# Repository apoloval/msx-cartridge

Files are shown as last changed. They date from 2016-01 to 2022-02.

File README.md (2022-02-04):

# MSX Cartridge

Some hardware specs (schematics + PCB designs) to build cartridges for MSX system.

This PCB can be used to mimic old cartridges for the MSX system. 
It will fit any ROM dump <64kb. Dumps larger than 64kb need a mapper, not implemented in this version.

EPROM supported is the SST39 family that can be bought for around 1.5€. This EPROM can be programmed with a standard TL866 programmer.







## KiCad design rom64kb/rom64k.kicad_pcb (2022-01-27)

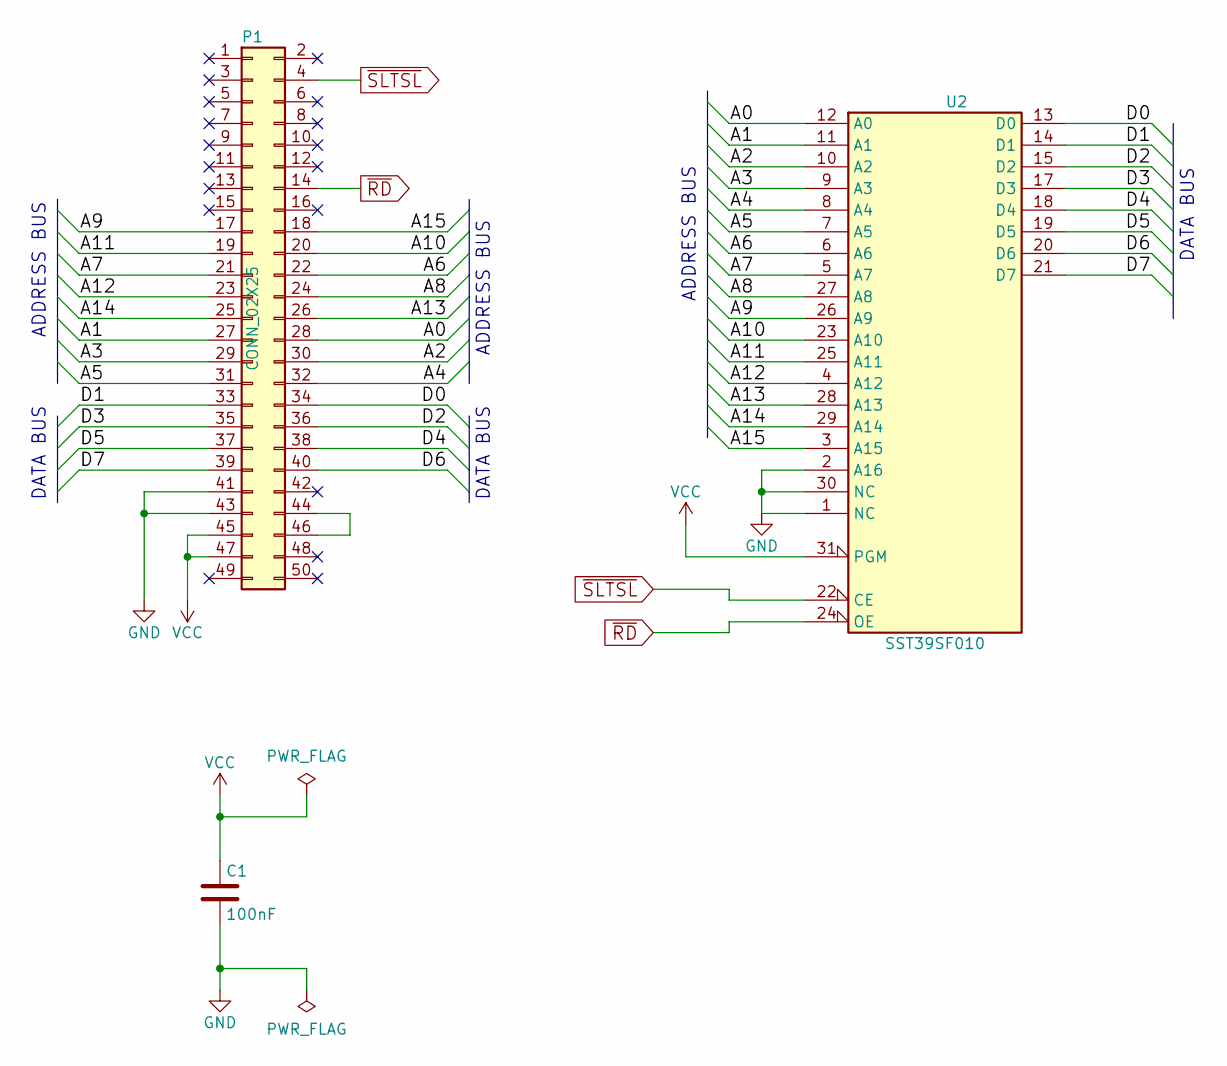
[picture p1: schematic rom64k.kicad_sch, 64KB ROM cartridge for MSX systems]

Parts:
C1: 100nF; C_Disc_D6_P5
P1: CONN_02X25; msx_cartridge
U2: SST39SF010; DIP-32_W15.24mm

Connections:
/A0: P1.28, U2.12 (A0)
/A1: P1.27, U2.11 (A1)
/A2: P1.30, U2.10 (A2)
/A3: P1.29, U2.9 (A3)
/A4: P1.32, U2.8 (A4)
/A5: P1.31, U2.7 (A5)
/A6: P1.22, U2.6 (A6)
/A7: P1.21, U2.5 (A7)
/A8: P1.24, U2.27 (A8)
/A9: P1.17, U2.26 (A9)
/A10: P1.20, U2.23 (A10)
/A11: P1.19, U2.25 (A11)
/A12: P1.23, U2.4 (A12)
/A13: P1.26, U2.28 (A13)
/A14: P1.25, U2.29 (A14)
/A15: P1.18, U2.3 (A15)
/D0: P1.34, U2.13 (D0)
/D1: P1.33, U2.14 (D1)
/D2: P1.36, U2.15 (D2)
/D3: P1.35, U2.17 (D3)
/D4: P1.38, U2.18 (D4)
/D5: P1.37, U2.19 (D5)
/D6: P1.40, U2.20 (D6)
/D7: P1.39, U2.21 (D7)
GND: C1.2, P1.41, P1.43, U2.1 (NC), U2.2 (A16), U2.16 (GND), U2.30 (NC)
unnamed: P1.44, P1.46
VCC: C1.1, P1.45, P1.47, U2.31 (PGM), U2.32 (VCC)
~RD: P1.14, U2.24 (OE)
~SLTSL: P1.4, U2.22 (CE)

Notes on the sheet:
DATA BUS
ADDRESS BUS

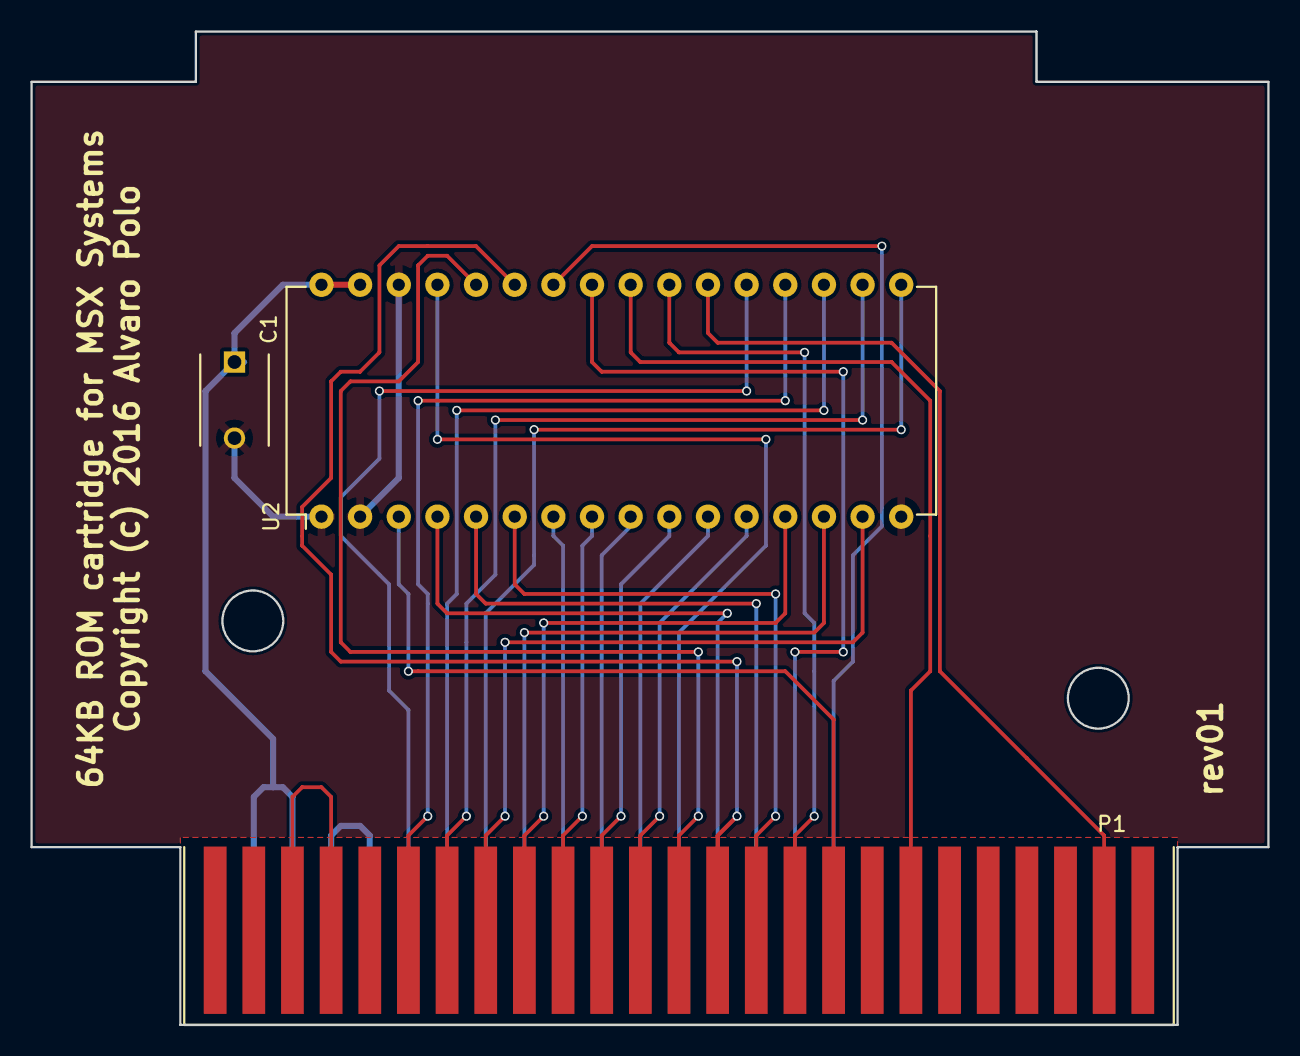
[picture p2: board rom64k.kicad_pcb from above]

Board: 2 copper layers, 81.3 x 65.3 mm, 3 parts (0 on the bottom side), 29 nets.

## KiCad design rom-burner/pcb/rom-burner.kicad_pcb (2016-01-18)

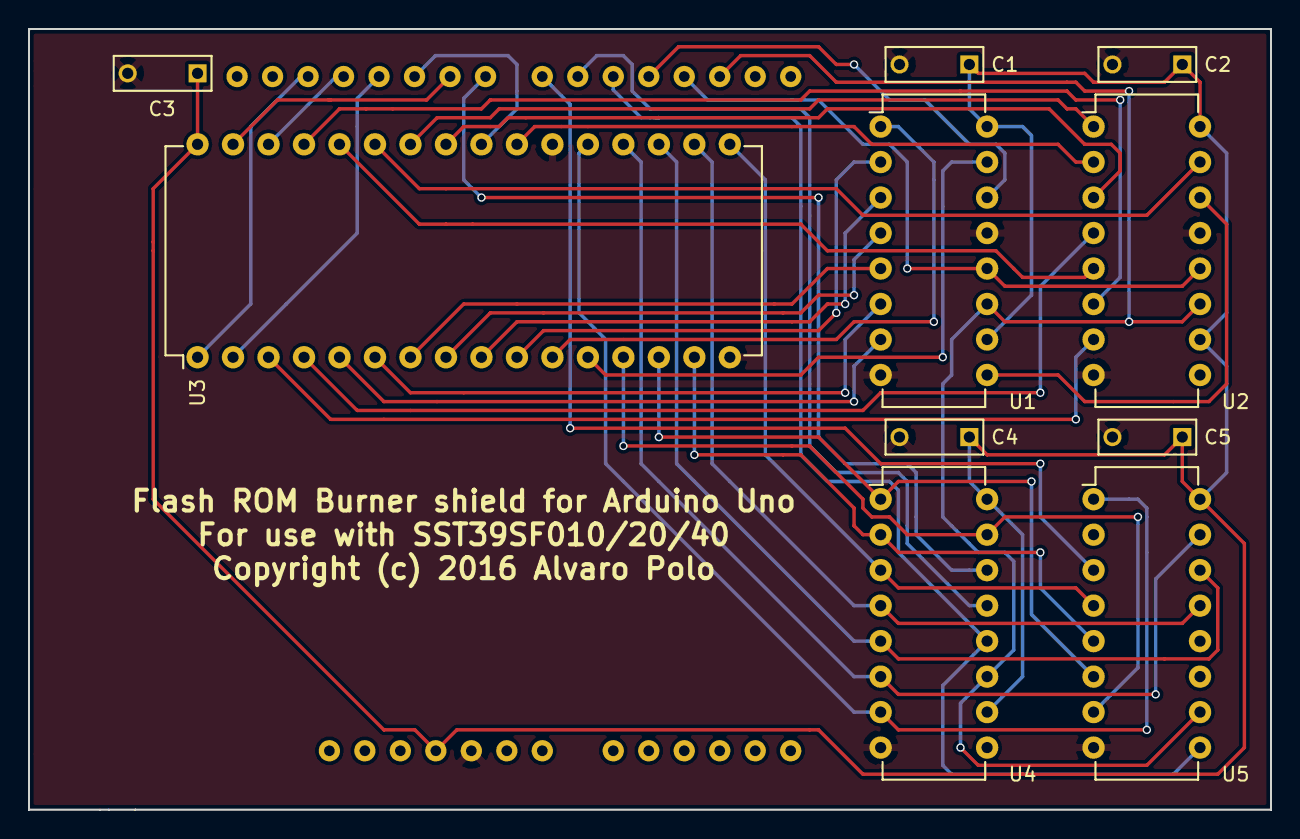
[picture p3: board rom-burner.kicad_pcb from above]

Board: 2 copper layers, 88.9 x 55.9 mm, 11 parts (0 on the bottom side), 39 nets.

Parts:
C1, C2, C3, C4, C5: 100nF; C_Rect_L7_W2.5_P5
U1, U2, U4: 74HC595; DIP-16_W7.62mm
U3: SST39SF010/20/40; DIP-32_W15.24mm
U5: 4021; DIP-16_W7.62mm
U6: Arduino_Uno_shield; arduino_uno_shield

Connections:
/A0: U1.15, U3.12
/A1: U1.1, U3.11
/A2: U1.2, U3.10
/A3: U1.3, U3.9
/A4: U1.4, U3.8
/A5: U1.5, U3.7
/A6: U1.6, U3.6
/A7: U1.7, U3.5
/A8: U2.15, U3.27
/A9: U2.1, U3.26
/A10: U2.2, U3.23
/A11: U2.3, U3.25
/A12: U2.4, U3.4
/A13: U2.5, U3.28
/A14: U2.6, U3.29
/A15: U2.7, U3.3
/DQ0: U3.13, U4.15, U5.7
/DQ1: U3.14, U4.1, U5.6
/DQ2: U3.15, U4.2, U5.5
/DQ3: U3.17, U4.3, U5.4
/DQ4: U3.18, U4.4, U5.13
/DQ5: U3.19, U4.5, U5.14
/DQ6: U3.20, U4.6, U5.15
/DQ7: U3.21, U4.7, U5.1
ADDR16: U3.2, U6.12
ADDR17: U3.30, U6.13
ADDR18: U3.1, U6.14
ADDR_DAT: U1.14, U6.5
ADDR_LATCH: U1.12, U2.12, U6.4
CLOCK: U1.11, U2.11, U4.11, U5.10, U6.3
DATA_DIR: U4.13, U6.7
DATA_IN: U5.3, U6.8
DATA_LATCH: U4.12, U5.9, U6.6
DATA_OUT: U4.14, U6.9
GND: C1.2, C2.2, C3.2, C4.2, C5.2, U1.8, U1.13, U2.8, U2.13, U3.16, U3.22, U4.8, U5.8, U6.21
unnamed: U1.9, U2.14
OE: U3.24, U6.11
VCC: C1.1, C2.1, C3.1, C4.1, C5.1, U1.10, U1.16, U2.10, U2.16, U3.32, U4.10, U4.16, U5.16, U6.20
WE: U3.31, U6.10

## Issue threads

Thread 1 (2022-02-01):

How to map ROM files to the 128 K flash

alex3331, 2022-02-01:
Hi, How many ROM images can I put on 128 k flash?
Can I put, say four of 32 k ROMS?

apoloval, 2022-02-03:
The 128KB cartridge is just a proof of concept. It was never tested. So first of all: USE IT AT YOUR OWN RISK!

Answering the question. The 3 jumpers are used to define the base address of the ROM that will be mapped by the cartridge, shifted 14 bits to the left. The goal of this is to write several games in the same cartridge, and control which one to use with the jumpers.

The following table summarizes the ROM offset mapped for each jumper value:

| Jumper value | ROM offset |
|--------------|------------|
| 0b000 | 0x00000 |
| 0b001 | 0x04000 |
| 0b010 | 0x08000 |
| 0b011 | 0x0C000 |
| 0b100 | 0x10000 |
| 0b101 | 0x14000 |
| 0b110 | 0x18000 |
| 0b111 | 0x1C000 |

How can you take advantage of this? Well, typically cartridges without mappers have a 16KB or 32KB ROM that respond to memory access at 0x4000 or 0x8000. So you could arrange your ROM data as follows:

| 16KB segment of ROM | Content |
| ---- |--- |
| 0 | Nothing, likely never used. |
| 1 | Game A page 1 (0x4000) |
| 2 | Game A page 2 (0x8000) |
| 3 | Game B page 1 (0x4000) |
| 4 | Game B page 2 (0x8000) |
| 5 | Game C page 2 (0x8000) |
| 6 | Game D page 1 (0x4000) |
| 7 | Game D page 2 (0x8000) |

In this example, games A, B and D are 32KB ROMS, while game C is just 16KB. You could play each one using the following jumper config

| Game | Jumper config |
| --- | --- |
| A | 0b000 |
| B | 0b010 |
| C | 0b011 |
| D | 0b100 |

The point is that if you want some page to be mapped at 0x4000, you have to calculate `ROM segment - 1` as jumper config. And if you want to map it at 0x8000, it is `ROM segment - 2`.

That's how you use that 128KB cartridge.

However, it is very likely this is not what you are looking for. But a kind of MegaROM with certain kind of mapper. If that's the case, you are lucky! I've been recently working on a solution to have a Konami-compatible (and also ASCII-compatible) cartridge of 128KB, and maybe more. You may find it in the `konami` Git branch. But it is still WIP. Watch this repo to receive news about its progress.

Everything clear now?

alex3331, 2022-02-03:
Yes, thank you for the clarification

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
--
Alex Shakhnovich

apoloval, 2022-02-04:
Alright! Please note the current method of mapping sections of the ROM might be not the best. And it could change in the future.

Closing this. If you have more questions, feel free to reopen.

Closed 2022-02-04.

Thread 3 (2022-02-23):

Mapping of Memory

alex3331, 2022-02-23:
After considering  at how 74LS283 works, I do  see that  SW3 with 128 K EEPROM is not effectively used.  Right now there are two 64 kB banks, each of them can be addressed at 0000, 4000, 8000  or C000. This is only 8 combinations of  A14, A15  and MA14, MA15, MA16  switches out of available 16.
It is possible to use 256 k or 512 k EEPROM. By the way - it is a lot easier and cheaper to buy SST 39SF040 (512 k) - other IC's (010 and 020) are backordered indefinitely. Let me know what you think.  8 and 32K games work fine, I am experimenting with larger games.
Let me know if I am wrong. Thanks

apoloval, 2022-04-21:
Yes, totally right. We are using only 3-bits to indicate the 16KB offset in the ROM. That only covers a ROM address space of 128KB. By adding another bit we could handle 256KBs.

However, let me insist that the 128KB design is incomplete. It was never tested in production. And not intended for use.

alex3331, 2022-04-21:
Hello,
I finally made this design work. I can put four programs up to 32 k each into a 128 k ROM. All I had to do is to change polarity around DIP switches. Everything works fine. I added 2 more DIP switches and now can use 512 k ROM to store and run 16 games. I need to update PCB but I do not have all of your libraries. I can share an updated schematics if you are interested.

Sent from my iPad

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

alex3331, 2022-04-21:
If you are interested - this works.

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

--
Alex Shakhnovich

apoloval, 2022-04-25:
What do you mean by _change polarity around DIP switches_?

retrolab-ad, 2022-10-14:
Hello.
Is there any 128k schematic working to share?
Thanks

apoloval, 2022-10-15:
> Is there any 128k schematic working to share?

Sorry, not yet.

retrolab-ad, 2022-10-15:
Gracias

El ds., 15 d’oct. 2022, 12:27, Alvaro Polo ***@***.***> va
escriure:

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

elosha, 2023-02-03:
@alex3331
> All I had to do is to change polarity around DIP switches.

Could you please elaborate on that what exactly you mean? Thanks 😃

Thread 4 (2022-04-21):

Is there a way to load the breakout project in Kicad?

alex3331, 2022-04-21:
Unable to load. because .sch file is shown as not valid.

apoloval, 2022-04-25:
What version of KiCAD are you using? This project was generated with KiCAD 6.

I am progressively migrating the rest of projects to that version. My recommendation is to update if you didn't yet.

apoloval, 2023-02-03:
I hope my last comment answered your question. Please feel free to reopen the issue otherwise.

Closed 2023-02-03.

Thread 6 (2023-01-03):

Less than 64KB on 64KB cartridge PCB

elosha, 2023-01-03:
_Edit: Nevermind, it seems I've ordered an old revision with 27C512 back then … but still interested to learn ;)_

I've already ordered your 64KB cartridge PCBs, but seeing other cartridge PCBs made me suspicious.

1. They require setting jumpers in order to use a 512Kbit ROM because of memory mapping, and other jumpers to use smaller ROMs because of different pinouts. Your layout even suggests a SST39SF010 and stays completely jumperless. How does memory mapping work?

Additionally, I've still got smaller EPROMs available. You wrote that ROMs with less than 64K are ok. Questions regarding replacing the SST39SF010, since pinouts are incompatible:

2. Is it correct that disconnecting pin `#30 NC` (≙ `#28 Vcc` on a DIP28 footprint) from the circuit and connecting it to _Vcc_ instead (making it a supply pin) simply allows using a 27C512, if aligned to the right?
3. Going further, connecting `#3 A15` (≙ `#1 Vpp` on DIP28) to _GND_ and `#29 A14` (≙ `#27 /PGM` on DIP28) to _Vcc_ instead would allow to fit a 27C256? But would it work in MSX memory mapping context?

apoloval, 2023-01-10:
There is no selectable memory mapping in this design. The first 64KBs of ROM memory are mapped to the 64KB memory space of the cartridge slot. The rest of ROM memory is not mapped. This is the simplest design ever possible for a ROM cartridge.

This was designed with the SST39SF0x0 chip in mind. For other ROM chips that use a different pinout, connections should be rewired accordingly, yes.

apoloval, 2023-02-03:
I hope my last comment answered your question. Please feel free to reopen the issue otherwise.

Closed 2023-02-03.

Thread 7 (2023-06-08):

Just a question..

atssada, 2023-06-08:
First of all, thank you so much sharing! really appreciated.

I ordered 64KB ROM PCB, and prepared SST 39SF010A (1MB Flash)..

And I programmed 32K rom by TL866  programmer (all default), and programming itself was successful..

But MSX can not run the 32K rom..

Any advice for me to investigate further?

Any MSX program to flash rom file?

Best,
Kim.

apoloval, 2023-06-08:
Perhaps you had written the ROM image to the wrong addresses.

The PCB is mapping the ROM memory in the 64KB address space of the cartridge slot as is. This means the address 0000h of the ROM chip corresponds to the address 0000h of the slot address.

The MSX, during BIOS boot, looks for a bootable program of slots only on memory pages 1 (at 4000h) and 2 (at 8000h). If you had written your program on address 0000h, it will never boot.

Try to manipulate your ROM image such that it is extended to 64KB, so it contains:
- 0000h to 3FFFh: fill with zeroes
- 4000h to 7FFFh: your program
- 8000h to FFFFh: fill with zeroes

For a program that expects to run on page 1. Or the following if it expects to run on page 2:
- 0000h to 7FFFh: fill with zeroes
- 8000h to BFFFh: your program
- C000h to FFFFh: fill with zeroes

Then write that ROM image to the 39SF and try again.

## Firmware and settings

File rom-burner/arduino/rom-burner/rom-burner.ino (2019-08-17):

#define PIN_CLOCK         2
#define PIN_ADDR_LATCH    3
#define PIN_ADDR_OUT      4
#define PIN_DATA_LATCH    5
#define PIN_DATA_READ     6
#define PIN_DATA_IN       7
#define PIN_DATA_OUT      8
#define PIN_WE            9
#define PIN_OE            10
#define PIN_ADDR16        11
#define PIN_ADDR17        12
#define PIN_ADDR18        13

#define SECTOR_SIZE       4096

#define COMMAND_READ      0
#define COMMAND_ERASE     1
#define COMMAND_WRITE     2
#define COMMAND_ERASEALL  3

#define SERIAL_BAUDRATE 921600

/** Put the given address in the bus through shift out registers. */
void put_addr(unsigned long addr) {
  digitalWrite(PIN_ADDR_LATCH, LOW);
  digitalWrite(PIN_CLOCK, LOW);
  shiftOut(PIN_ADDR_OUT, PIN_CLOCK, MSBFIRST, (byte) (addr >> 8));
  shiftOut(PIN_ADDR_OUT, PIN_CLOCK, MSBFIRST, (byte) addr);
  digitalWrite(PIN_ADDR16, bitRead(addr, 16));
  digitalWrite(PIN_ADDR17, bitRead(addr, 17));
  digitalWrite(PIN_ADDR18, bitRead(addr, 18));
  digitalWrite(PIN_ADDR_LATCH, HIGH);
}

/** Put the given data in the bus through shift out registers. */
void put_data(byte data) {
  digitalWrite(PIN_DATA_LATCH, LOW);
  digitalWrite(PIN_CLOCK, LOW);
  shiftOut(PIN_DATA_OUT, PIN_CLOCK, MSBFIRST, (byte) data);
  digitalWrite(PIN_DATA_LATCH, HIGH);
}

/** Get data from the data bus. */
byte get_data() {
  digitalWrite(PIN_OE, LOW);
  digitalWrite(PIN_CLOCK, HIGH);
  digitalWrite(PIN_DATA_LATCH, HIGH);
  digitalWrite(PIN_DATA_LATCH, LOW);
  digitalWrite(PIN_OE, HIGH);
  return shiftIn(PIN_DATA_IN, PIN_CLOCK, MSBFIRST);
}

/** Send a command to the ROM device. */
void send_cmd_seq(unsigned long* addr, byte* data, unsigned len) {
  digitalWrite(PIN_DATA_READ, LOW);
  digitalWrite(PIN_OE, HIGH);
  for (int i = 0; i < len; i++) {
    put_addr(addr[i]);
    digitalWrite(PIN_WE, LOW);
    put_data(data[i]);
    digitalWrite(PIN_WE, HIGH);
  }
  digitalWrite(PIN_DATA_READ, HIGH);
}

/** Read the content of given ROM device address. */
byte read_addr(unsigned long addr) {
  put_addr(addr);
  return get_data();
}

/** Wait for write/erase operation using data polling method. */
void wait_datapolling(byte data) {
  for (;;) {
    byte recv = get_data();
    if ((recv & 0x80) == (data & 0x80))
      return;
  }
}

/**
 * Write the content of the given ROM device address
 * with the given byte.
 */
void write_addr(unsigned long addr, byte data) {
  unsigned long addr_seq[] = { 0x5555, 0x2aaa, 0x5555, addr };
  byte data_seq[] = { 0xaa, 0x55, 0xa0, data };
  send_cmd_seq(addr_seq, data_seq, 4);
  wait_datapolling(data);
}

/**
 * Perform a blank test, returning the number of bytes that
 * are not equal to 0xff.
 */
int blank_test(byte sector) {
  unsigned long sector_addr = ((unsigned long) sector) << 12;
  int result = 0;
  for (int i = 0; i < SECTOR_SIZE; i++) {
    unsigned long addr = sector_addr + i;
    byte actual = read_addr(addr);
    if (actual != 0xff) {
      result++;
    }
  }
  return result;
}

/** Erase the whole memory. */
int erase_all() {
  unsigned long addr_seq[] = { 0x5555, 0x2aaa, 0x5555, 0x5555, 0x2aaa, 0x5555 };
  byte data_seq[] = { 0xaa, 0x55, 0x80, 0xaa, 0x55, 0x10 };
  send_cmd_seq(addr_seq, data_seq, 6);
  delay(500);
  return blank_test(0);
}

/** Erase the given sector. */
int erase_sector(byte sector) {
  unsigned long sector_addr = ((unsigned long) sector) << 12;
  unsigned long addr_seq[] = { 0x5555, 0x2aaa, 0x5555, 0x5555, 0x2aaa, sector_addr };
  byte data_seq[] = { 0xaa, 0x55, 0x80, 0xaa, 0x55, 0x30 };
  send_cmd_seq(addr_seq, data_seq, 6);
  delay(20);
  return blank_test(sector);
}

/** Read a single byte from serial, waiting if none has arrived yet. */
byte serial_read_byte() {
  while (Serial.available() < 1) {}
  return Serial.read();
}

/** Process a incoming read command from serial. */
void process_read_command() {
  unsigned long sector_addr = ((unsigned long) serial_read_byte()) << 12;
  for (int i = 0; i < SECTOR_SIZE; i++) {
    unsigned long addr = sector_addr + i;
    byte data = read_addr(addr);
    Serial.write(data);
  }
}

/** Process a incoming erase command from serial. */
void process_erase_command() {
  byte sector = serial_read_byte();
  Serial.write(erase_sector(sector));
}

/** Process a incoming erase command from serial. */
void process_eraseall_command() {
  Serial.write(erase_all());
}

/** Process a incoming write command from serial. */
void process_write_command() {
  unsigned long sector_addr = ((unsigned long) serial_read_byte()) << 12;
  for (int i = 0; i < SECTOR_SIZE; i++) {
    unsigned long addr = sector_addr + i;
    byte data = serial_read_byte();
    write_addr(addr, data);
    Serial.write(data);
  }
}

/** Process a incoming command from serial. */
void process_command() {
  switch (serial_read_byte()) {
    case COMMAND_READ:
      process_read_command();
      break;
    case COMMAND_ERASE:
      process_erase_command();
      break;
    case COMMAND_WRITE:
      process_write_command();
      break;
    case COMMAND_ERASEALL:
      process_eraseall_command();
      break;
  }
}

void setup() {
  pinMode(PIN_CLOCK, OUTPUT);
  pinMode(PIN_ADDR_LATCH, OUTPUT);
  pinMode(PIN_ADDR_OUT, OUTPUT);
  pinMode(PIN_DATA_LATCH, OUTPUT);
  pinMode(PIN_DATA_READ, OUTPUT);
  pinMode(PIN_DATA_IN, INPUT);
  pinMode(PIN_DATA_OUT, OUTPUT);
  pinMode(PIN_WE, OUTPUT);
  pinMode(PIN_OE, OUTPUT);
  pinMode(PIN_ADDR16, OUTPUT);
  pinMode(PIN_ADDR17, OUTPUT);
  pinMode(PIN_ADDR18, OUTPUT);

  digitalWrite(PIN_ADDR_LATCH, LOW);
  digitalWrite(PIN_DATA_LATCH, LOW);
  digitalWrite(PIN_DATA_READ, HIGH);
  digitalWrite(PIN_WE, HIGH);
  digitalWrite(PIN_OE, HIGH);
  delay(100);

  Serial.begin(SERIAL_BAUDRATE);
  Serial.write("ROM-BURNER");
}

void loop() {
  process_command();
}

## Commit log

2015-12-30 Add initial files for ROM128K project
    [rom128k.kicad_pcb, rom128k.sch]
2016-01-18 Complete 128KB ROM cartridge schematics & PCB
    [rom128k.kicad_pcb, rom128k.sch]
2016-01-18 Introduce schematics & PCB for a ROM burner device
    [rom-burner.kicad_pcb, rom-burner.sch]
2016-08-07 Import rom burner Arduino sketch from rom-burner repo
    [rom-burner.ino]
2016-08-07 Adapt rom-burner Arduino sketch to use 18 bit addresses
    [rom-burner.ino]
2016-08-07 Move rom-burner pcb files to its own directory
    [rom-burner.kicad_pcb, rom-burner.sch]
2016-08-07 Increase baud rate used in rom burner
    [rom-burner.ino]
2016-08-09 Remove net files
    They can (and must) be regenerated from the schematics.
2016-08-09 Add Kicad project for a ROM cartridge of 64KB
    [rom64k.kicad_pcb, rom64k.sch]
2016-08-09 Fix missing tracks in ROM 64KB
    [rom64k.kicad_pcb]
2016-08-30 Use a baud rate in burner compatible with Mac OS X
    [rom-burner.ino]
2019-08-17 Fix obsolete schematic for ROM burner
    [rom-burner.sch]
2019-08-17 [rom-burner] Wait for writes using data polling
    [rom-burner.ino]
2022-01-27 [rom64] Adapt the design to KiCAD 6
    [rom64k-2022-01-27-09-36-20.sch, rom64k-2022-01-27-10-36-40.sch, rom64k.kicad_pcb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]
2022-03-25 cartridge-breakout: new project
    [cartridge-breakout.kicad_pcb, cartridge-breakout.kicad_sch]

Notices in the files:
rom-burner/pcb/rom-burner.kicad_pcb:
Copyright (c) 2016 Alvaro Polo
